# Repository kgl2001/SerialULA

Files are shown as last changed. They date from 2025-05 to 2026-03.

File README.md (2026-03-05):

# Acorn BBC Micro Serial ULA Replacement
This module designed as a drop in replacement for the Serial Interface IC, 2C199 (IC7) on the BBC Micro.

Some general notes:

* The source files are to be used with KiCAD v9.0.0 or later.
* The gerber files have been optimised for fabrication by JLCPCB. In particular, there is a 8mmx8mm silkscreen box on the rear of the PCB. This is to allow a 2D barcode, with unique serial number to be printed on the PCB.
* If you want the barcode to be added, then make sure to select this option in the 'Mark on PCB' field, and make sure to select 'Specify position' in the '2D Barcode Position' field, otherwise you will end up with a white 8mm x 8mm box printed on your PCB and a 8mm x 8mm barcode printed at a position of JLCPCBs choosing. Thrust me on this!
* If you don't want the barcode added, then remove the 8mm x 8mm box from the silkscreen layer and regenerate the gerbers. Otherwise you will end up with a white 8mm x 8mm box printed on your PCB.
* A combined CPL / BOM file is included in the gerber directory. Again, this is for use with JLCPCB, if you want to use their PCBA (PCB Assembly) to solder on all the SMD parts.
* The CPL / BOM file includes two different options for LDO regulator and associated capacitors. Select one set only - either U2, C2.1 & C2.2 OR U3, C4 & C5. If using JLCPCB for assembly, you can deselect one set during the PCBA ordering process.
* You will need to source suitable round pin headers, and solder these onto the underside of the PCB. These headers will then plug into IC socket 7 on the beeb motherboard.

Please refer to the following discussion on Stardot for further details: https://stardot.org.uk/forums/viewtopic.php?t=30963

## Schematic
SerialULA

## Author

The Serial ULA Replacement module is developed and maintained by Ken Lowe.
    
## Hardware License (Creative Commons BY-SA 4.0)

Please see the following link for details: https://creativecommons.org/licenses/by-sa/4.0/

You are free to:

Share - copy and redistribute the material in any medium or format
Adapt - remix, transform, and build upon the material
for any purpose, even commercially.

This license is acceptable for Free Cultural Works.

The licensor cannot revoke these freedoms as long as you follow the license terms.

Under the following terms:

Attribution - You must give appropriate credit, provide a link to the license, and indicate if changes were made. You may do so in any reasonable manner, but not in any way that suggests the licensor endorses you or your use.

ShareAlike - If you remix, transform, or build upon the material, you must distribute your contributions under the same license as the original.

No additional restrictions - You may not apply legal terms or technological measures that legally restrict others from doing anything the license permits.

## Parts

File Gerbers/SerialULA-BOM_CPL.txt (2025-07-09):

Designator	LCSC Part #	Footprint	JLCValue	Mid X	Mid Y	Rotation	Layer	Val	Package
C1	C1525	0402	100n	87.9906	-65.0698	0	top	100n	C_0402_1005Metric
C2	C1525	0402	100n	91.163	-62.225	0	top	100n	C_0402_1005Metric
C2.1	C7171	CASE-A_3216	10uF	90.429	-41.905	-90	top	10uF	CP_EIA-3216-18_Kemet-A
C2.2	C7171	CASE-A_3216	10uF	90.429	-46.8834	90	top	10uF	CP_EIA-3216-18_Kemet-A
C3	C1525	0402	100n	91.191	-50.541	0	top	100n	C_0402_1005Metric
C4	C52923	0402	1u	84.206	-40.508	180	top	1u	C_0402_1005Metric
C5	C52923	0402	1u	84.206	-45.969	180	top	1u	C_0402_1005Metric
R1	C4109	0402	2K0	84.333	-47.493	180	top	2K0	R_0402_1005Metric
R2	C25871	0402	1K8	87.381	-48.634	-90	top	1K8	R_0402_1005Metric
R3	C11702	0402	1K0	86.238	-48.636	-90	top	1K0	R_0402_1005Metric
R4	C4109	0402	2K0	82.301	-47.493	180	top	2K0	R_0402_1005Metric
R5	C25862	0402	1K2	83.063	-65.019	180	top	1K2	R_0402_1005Metric
R6	C11702	0402	1K0	81.031	-65.019	0	top	1K0	R_0402_1005Metric
R7	C25744	0402	10K	84.7394	-64.13	-90	top	10K	R_0402_1005Metric
R8	C25744	0402	10K	86.5174	-64.13	-90	top	10K	R_0402_1005Metric
U1	C569042	LQFP-44	XC9572XL-10VQG44C	85.603	-56.383	-90	top	XC9572XL-10VQG44C	LQFP-44_10x10mm_P0.8mm
U2	C6186	SOT-223-3	AMS1117-3.3	84.206	-43.302	0	top	AMS1117-3.3	SOT-223-3_TabPin2
U3	C5446	SOT-23-3	XC6206P332MR	84.206	-43.302	-90	top	XC6206P332MR	SOT-23-3

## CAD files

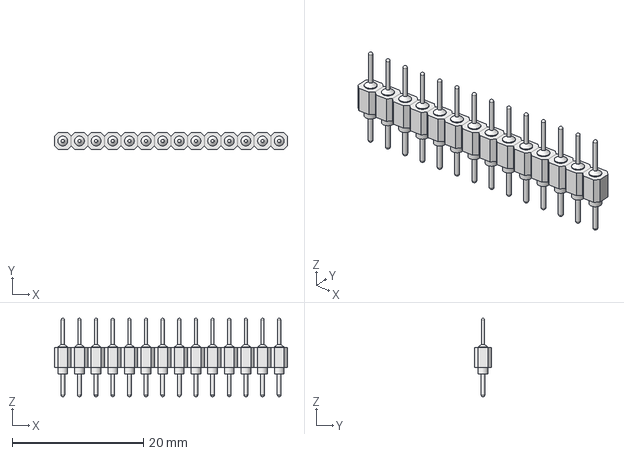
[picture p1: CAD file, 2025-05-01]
3DModels/Header-Male-round 14 pin.step
35.6 x 2.54 x 12.0 mm

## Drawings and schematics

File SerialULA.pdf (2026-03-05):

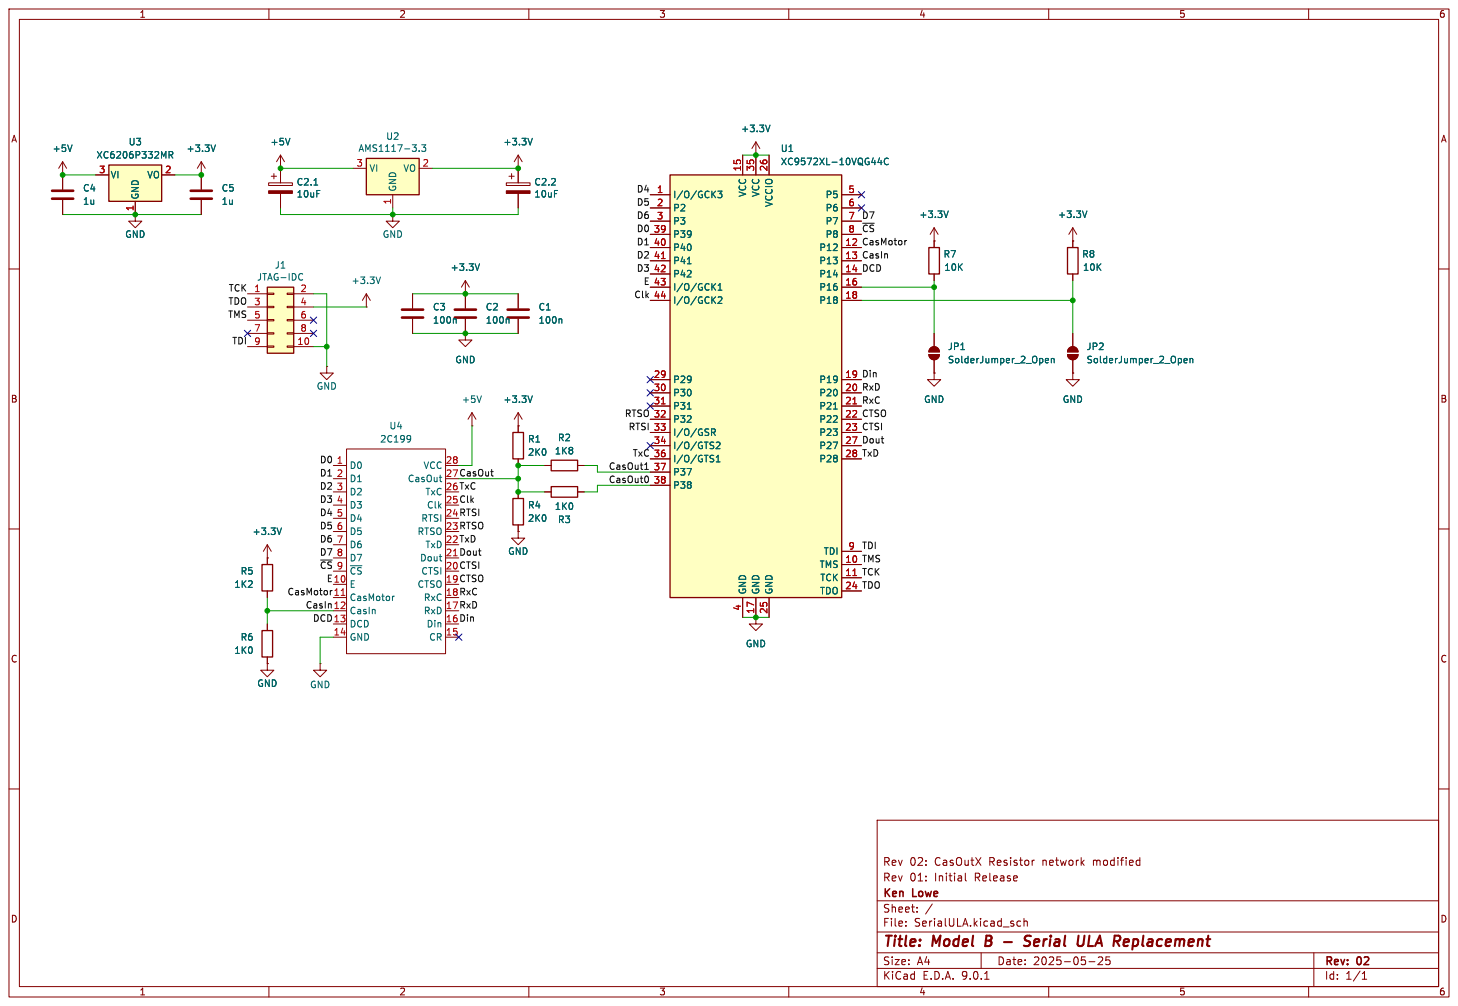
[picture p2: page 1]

4 VCC 35 GND 17 VCCIO 26 GND 25 P5 5 P6 6 P7 7 P8 8 P12 12 P13 13 P14 14 P16 16 P18 18 P19 19 P20 20 P21 21 P22 22 P23 23 P27 27 P28 28 TDI 9 TMS 10 TCK 11 TDO 24 U1XC9572XL-10VQG44C

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

CasMotor CasIn ~{CS} D7 TxC

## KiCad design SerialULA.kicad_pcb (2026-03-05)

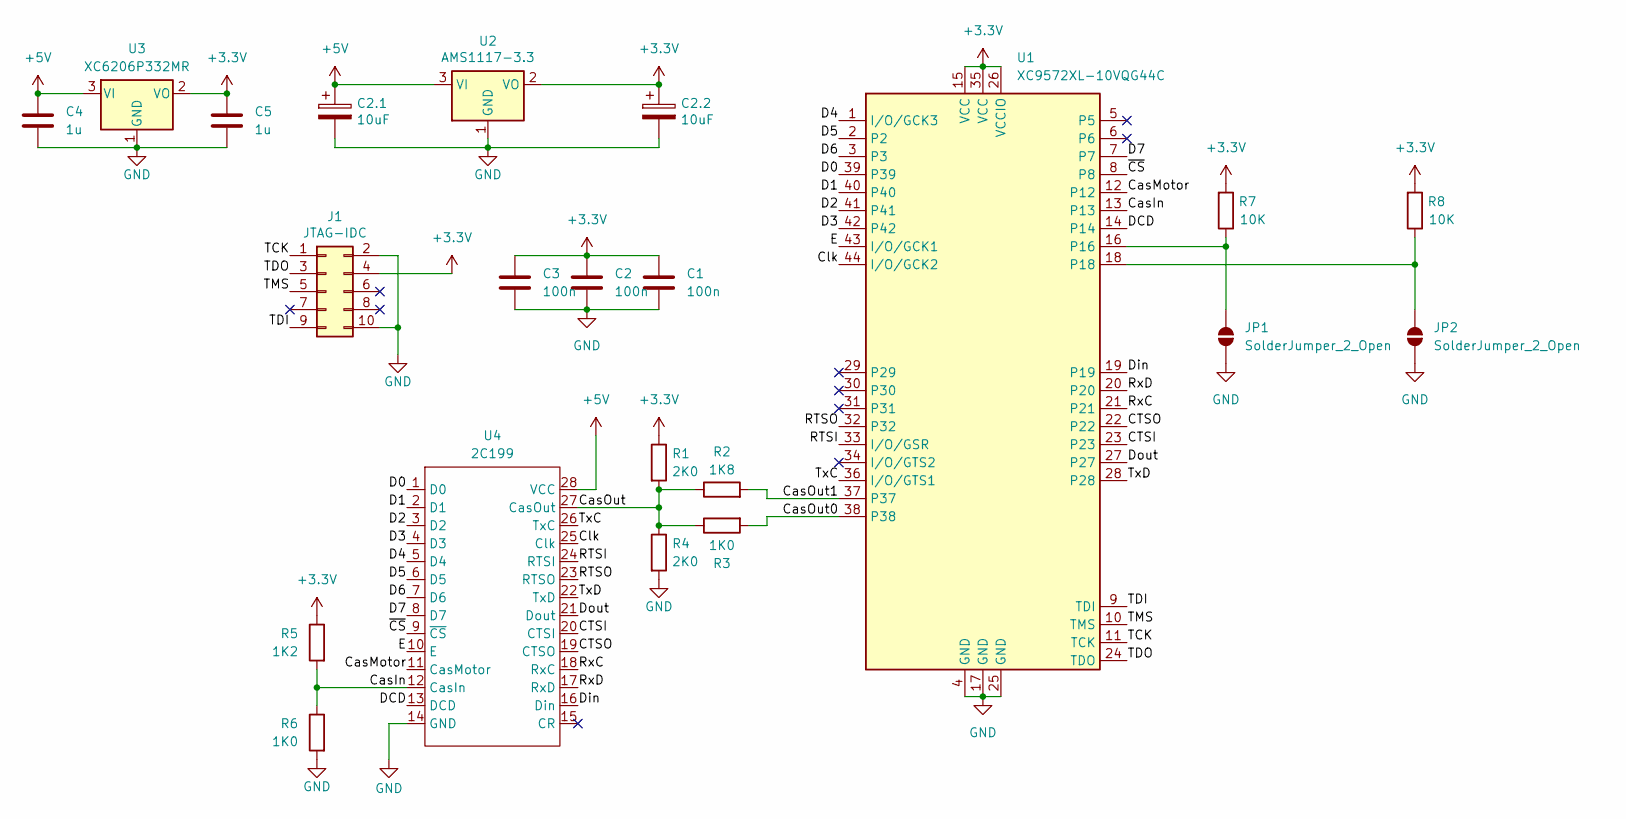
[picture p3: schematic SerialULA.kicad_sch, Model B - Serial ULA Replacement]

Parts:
C1, C2, C3: 100n; C_0402_1005Metric; JLC Part Number C1525
C2.1, C2.2: 10uF; CP_EIA-3216-18_Kemet-A; JLC Part Number C7171
C4, C5: 1u; C_0402_1005Metric; JLC Part Number C52923
J1: JTAG-IDC; PinHeader_2x05_P2.54mm_Vertical
JP1, JP2: SolderJumper_2_Open; SolderJumper-2_P1.3mm_Open_RoundedPad1.0x1.5mm
R1, R4: 2K0; R_0402_1005Metric; JLC Part Number C4109
R2: 1K8; R_0402_1005Metric; JLC Part Number C25871
R3, R6: 1K0; R_0402_1005Metric; JLC Part Number C11702
R5: 1K2; R_0402_1005Metric; JLC Part Number C25862
R7, R8: 10K; R_0402_1005Metric; JLC Part Number C25744
U1: XC9572XL-10VQG44C; LQFP-44_10x10mm_P0.8mm; JLC Part Number C569042
U2: AMS1117-3.3; SOT-223-3_TabPin2; JLC Part Number C6186
U3: XC6206P332MR; SOT-23-3; JLC Part Number C5446
U4: 2C199; DIP-28_W15.24mm

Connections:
+3.3V: C1.1, C2.1, C2.2.1, C3.1, C5.1, J1.4, R1.1, R5.1, R7.2, R8.2, U1.15 (VCC), U1.26 (VCCIO), U1.35 (VCC), U2.2 (VO), U3.2 (VO)
+5V: C2.1.1, C4.1, U2.3 (VI), U3.3 (VI), U4.28 (VCC)
/CTSI: U1.23, U4.20 (CTSI)
/CTSO: U1.22, U4.19 (CTSO)
/CasIn: R5.2, R6.1, U1.13, U4.12 (CasIn)
/CasMotor: U1.12, U4.11 (CasMotor)
/CasOut: R1.2, R2.1, R3.1, R4.1, U4.27 (CasOut)
/CasOut0: R3.2, U1.38
/CasOut1: R2.2, U1.37
/Clk: U1.44 (I/O/GCK2), U4.25 (Clk)
/D0: U1.39, U4.1 (D0)
/D1: U1.40, U4.2 (D1)
/D2: U1.41, U4.3 (D2)
/D3: U1.42, U4.4 (D3)
/D4: U1.1 (I/O/GCK3), U4.5 (D4)
/D5: U1.2, U4.6 (D5)
/D6: U1.3, U4.7 (D6)
/D7: U1.7, U4.8 (D7)
/DCD: U1.14, U4.13 (DCD)
/Din: U1.19, U4.16 (Din)
/Dout: U1.27, U4.21 (Dout)
/E: U1.43 (I/O/GCK1), U4.10 (E)
/RTSI: U1.33 (I/O/GSR), U4.24 (RTSI)
/RTSO: U1.32, U4.23 (RTSO)
/RxC: U1.21, U4.18 (RxC)
/RxD: U1.20, U4.17 (RxD)
/TCK: J1.1, U1.11 (TCK)
/TDI: J1.9, U1.9 (TDI)
/TDO: J1.3, U1.24 (TDO)
/TMS: J1.5, U1.10 (TMS)
/TxC: U1.36 (I/O/GTS1), U4.26 (TxC)
/TxD: U1.28, U4.22 (TxD)
/~CS: U1.8, U4.9 (~CS)
GND: C1.2, C2.2, C2.1.2, C2.2.2, C3.2, C4.2, C5.2, J1.2, J1.10, JP1.1 (A), JP2.1 (A), R4.2, R6.2, U1.4 (GND), U1.17 (GND), U1.25 (GND), U2.1 (GND), U3.1 (GND), U4.14 (GND)
unnamed: JP1.2 (B), R7.1, U1.16
unnamed: JP2.2 (B), R8.1, U1.18

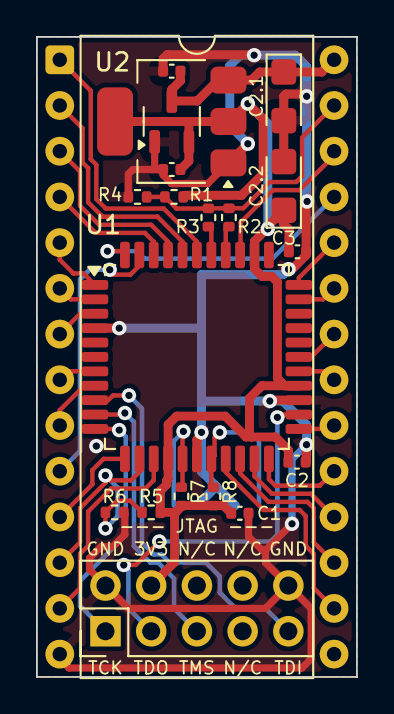
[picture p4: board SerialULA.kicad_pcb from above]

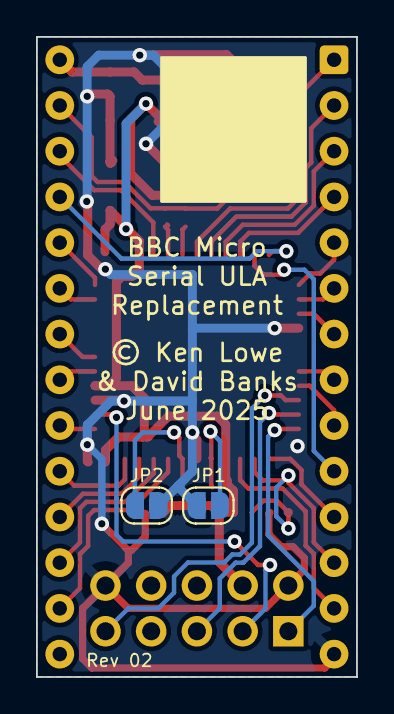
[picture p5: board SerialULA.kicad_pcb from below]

Board: 2 copper layers, 17.8 x 35.6 mm, 22 parts (2 on the bottom side), 36 nets.

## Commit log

2025-06-22 Initial commit of Rev 02 hardware
    - Dual footprint for both large and small LDO regulator / capacitors.
    - Updated resistor values at R1, R2, R3 & R4 for CasOutX. Now pulling up to 3.3V instead of 5V
    - Connected extra solder bridge with pull up into spare CPLD input for possible future 'extended features'.
    [SerialULA.kicad_pcb, SerialULA.kicad_sch]
2025-06-22 Delete SerialULA.drl
    File relocated to Gerbers directory
    [SerialULA.drl]
2025-07-09 Fix BOM / CPL xlsx file
    Also add tab delimited version
    [SerialULA-BOM_CPL.xlsx]
2026-03-05 Revert commit 2e120ae
    Restore original Rev 01 CPL / BOM file
    [SerialULA-BOM_CPL.xlsx]
2026-03-05 Revert commit 2e120ae
    Delete Gerbers/SerialULA-BOM_CPL.txt
2026-03-05 Fix BOM / CPL file
    Fix SerialULA-BOM_CPL.xlsx file
    Add SerialULA-BOM_CPL.txt file
    [SerialULA-BOM_CPL.xlsx]
2026-03-05 Update README.md
    Add schematic

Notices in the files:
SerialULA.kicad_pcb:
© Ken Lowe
